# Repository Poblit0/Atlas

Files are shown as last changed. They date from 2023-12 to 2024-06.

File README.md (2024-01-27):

# MiniAtlas
Projet de robotique Polytech - Promotion ROB3 2023/2024

De DELFLY Agathe et MAUVOISIN Paul

## Idée principale
Créer des robots d'entrepôt autonomes capables de stocker et restituer des colis grâce à Arduino

## Motivations
Ce premier projet a pour objectif de nous faire découvrir divers aspects de la robotique

Les problématiques de ce robot semblent couvrir un panel de fondamentaux :
- Un système de déplacement dans l’espace
- Un système de préhension capable de manipuler des colis
- Une mémoire contenant l’emplacement des colis enregistrés
- Un système de communication pour échanger avec ses homologues

## Origine du nom
Le robot transporte les colis sur sa face supérieure, ce qui peut être considéré comme son dos
    
Cette position nous rappelait le mythe d'Atlas qui portait la Terre sur son dos, d'où le choix de ce nom pour notre robot

## Matériel (par robot)
### Carte électronique
- 1 carte Arduino UNO
- 1 pont en H

### Moteurs
- 2 servomoteurs
- 2 moteurs CC
  
### Capteurs
- 5 capteurs IR

### Modules
- 1 module de communciations RF

### Matériels complémentaires
- 1 interrupteur
- 1 boîtier d'alimentation
- 1 roulette à billes

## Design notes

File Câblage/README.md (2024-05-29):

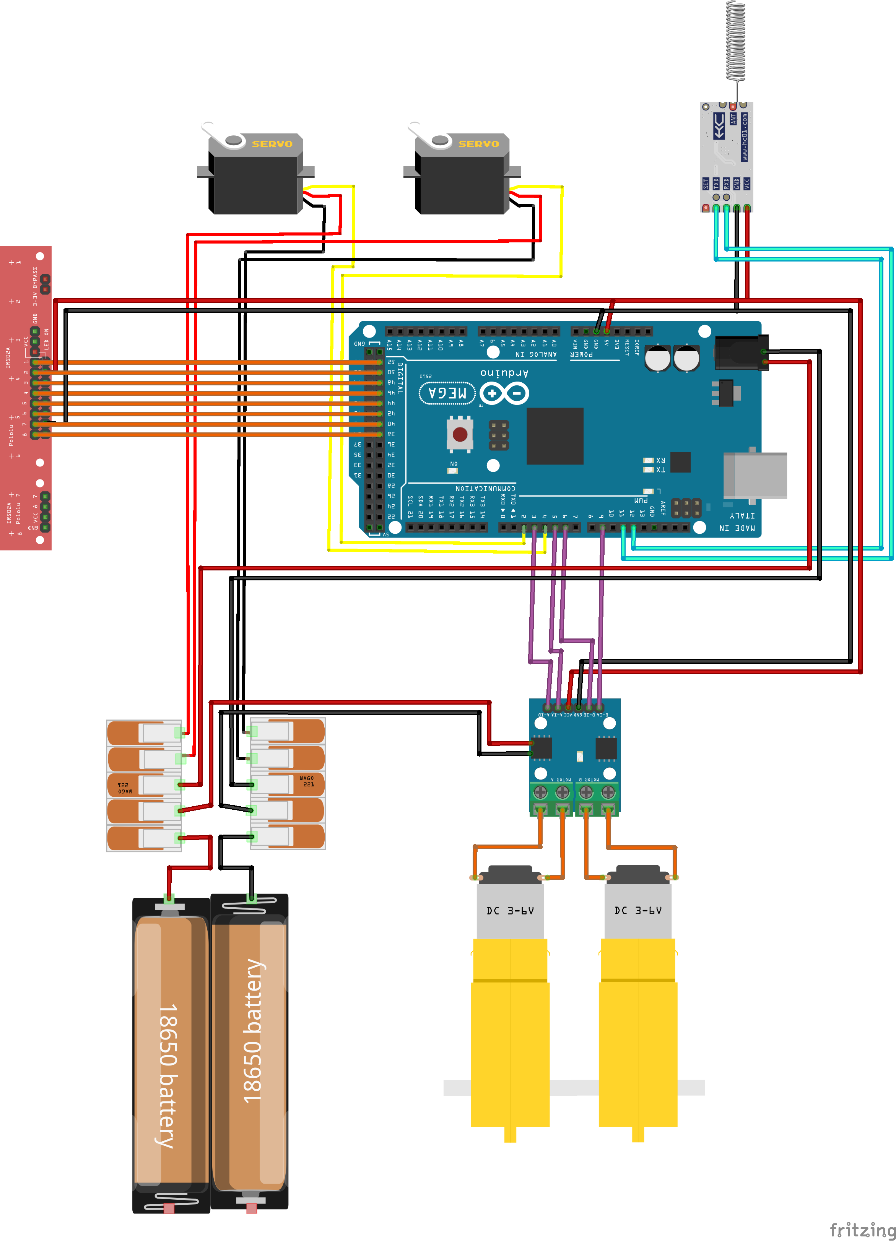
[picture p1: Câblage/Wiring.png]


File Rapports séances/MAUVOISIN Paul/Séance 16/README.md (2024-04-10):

## Forums pour envoyer des données de l'Arduino vers la Jetson

[Forum Nvidia](https://forums.developer.nvidia.com/t/questions-on-jetson-nano-arduino-i2c-communication/111277/3)

[Forum Arduino](https://forum.arduino.cc/t/arduino-jetson-nano-i2c-communication-failure/1008558)

## Librairies sources

['smbus'](https://pypi.org/project/smbus2/) pour Python

['Wire'](https://www.arduino.cc/reference/en/language/functions/communication/wire/) pour Arduino

## Vidéos d'explication pour l'usage des librairies

[pour l'utilisation de Wire](https://www.youtube.com/watch?v=2W4lViDKhpE)

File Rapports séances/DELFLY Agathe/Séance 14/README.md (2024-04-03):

## Suivi de ligne avec PID



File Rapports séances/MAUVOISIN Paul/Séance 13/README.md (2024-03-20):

## Liens utilisés pour le contrôle des servomoteurs
1er [Lien GitHub](https://github.com/JetsonHacksNano/ServoKit) pour le contrôle des servomoteurs

2nde [Vidéo tutorielle](https://www.youtube.com/watch?v=8YKAtpPSEOk&ab_channel=PaulMcWhorter) pour tenter de contourner l'erreur du 1er lien

## GIF de la Téléopération
Précisions :
- Le joystick de droite pilote la roue droite, respectivement à gauche, ce qui explique pourquoi le robot ne se déplace que de cette manière, car je filme avec mon téléphone dans la main gauche.
- Le joystick est très sensible, ce qui explique pourquoi de légers mouvements font bouger le robot si rapidemment.



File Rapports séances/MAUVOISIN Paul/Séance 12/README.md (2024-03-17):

# Sources retenues

## Réaliser le suivi de ligne par caméra
- [Lien le plus direct](https://jetbot.org/master/examples/road_following.html), par Nvidia JetBot eux-mêmes
- [Vidéo explicative et détaillée](https://www.youtube.com/watch?v=VY7m4lPIOj0&ab_channel=NVIDIADeveloper) du lien Nvidia précédent
- [Un répertoire GitHub](https://github.com/abuelgasimsaadeldin/Jetbot-Road-Following-and-Collision-Avoidance) qui permettra, à termes, la fusion du suivi de ligne et l'évitement d'obstacle qui pourrait être utile

## Actionner les servomoteurs
- [Site internet](https://jetsonhacks.com/2019/07/22/jetson-nano-using-i2c/), où se trouve également une vidéo pour comprendre l'utilisation des servomoteurs à travers un bus I2C et le PCA9685
- [Seconde vidéo](https://www.youtube.com/watch?v=8YKAtpPSEOk&ab_channel=PaulMcWhorter), permettant de prendre en mains les servomoteurs avec le même matériel

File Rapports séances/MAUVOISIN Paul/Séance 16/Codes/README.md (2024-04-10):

### Le fichier "Master.txt" est le code Python de la Jetson Nano

### Le fichier "Slave.ino" est le code Arduino

*Les dénominations Master et Slave font références aux rôles de chacune des cartes dans la communication I2C*

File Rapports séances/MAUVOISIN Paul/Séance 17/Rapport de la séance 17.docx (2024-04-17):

Rapport de la séance 17

16 avril 2024

Objectif de séance :

- Réaliser le code pour la communication I2C entre Arduino et Jetson Nano
- Réaliser le suivi de ligne par caméra à la place du suivi de route

Tout d’abord, après ma documentation sur les librairies ‘smbus’ pour Python et ‘Wire’ pour Arduino, je suis parvenu à obtenir un code fonctionnel.

Celui-ci fonctionne avec un capteur IR branché sur l’Arduino.

Si le capteur voit du noir, la communication I2C permet à la Jetson de recevoir l’information et affichera ‘True’, à l’inverse, elle affichera ‘False’ si le captera ne voit pas du noir.

Les codes (Python et Arduino) sont fournis dans le répertoire de la séance 17.

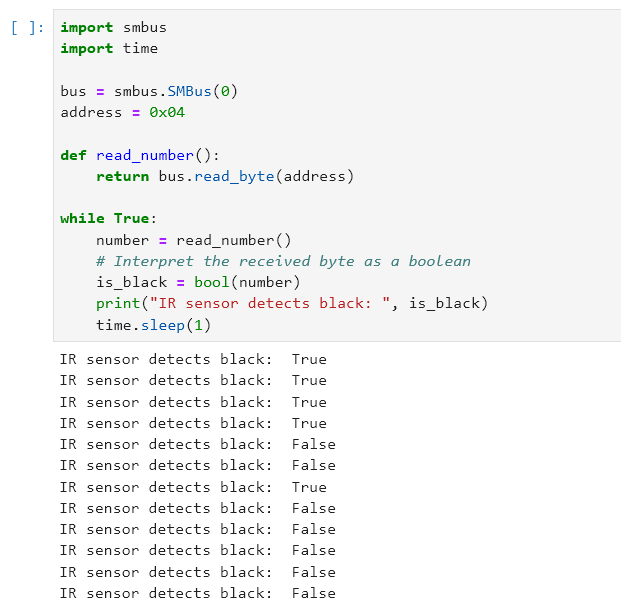
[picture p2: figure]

L’objectif sera de placer des marqueurs noirs détectés par le capteur IR pour arrêter les moteurs du moteur pendant le dépôt ou la réception d’un colis.

J’ai ensuite pris les photos pour réaliser le suivi de ligne par caméra. Or, avec la même quantité de photo que pour le suivi de route, soit 200 photos, le résultat n’est pas très concluant. Il sera donc nécessaire de faire plus de photos pour réessayer le suivi de ligne, car il est préférable que nos 2 robots suivent une ligne, plutôt que l’un suive une ligne et l’autre une route, ce qui rendrait incompatible leur déplacement dans l’environnement de l’autre.

Cependant, dû au réseau de l’école, la latence entre la réalité et l’affichage de la caméra ne rend pas l’opération, de prendre les photos, fluides. C’est pourquoi je prendrai les autres photos depuis le réseau de mon domicile et je vais me renseigner maintenant sur l’achat d’un tapis avec un motif imprimé.

Si le suivi de ligne fonctionne, il sera possible de faire imprimer sur tapis via le site PixartPrinting, un entrepôt avec des dimensions parfaites et sans imperfections.

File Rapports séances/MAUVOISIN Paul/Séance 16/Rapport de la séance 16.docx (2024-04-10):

Rapport de la séance 16

9 avril 2024

Objectif de séance :

- Résoudre le problème de l’importation de ‘smbus’ pour réaliser la connexion I2C
- Imprimer des meilleurs supports servomoteurs
- Créer un code pour qu’un capteur IR connecté à l’Arduino mette en fonction le suivi de route du robot avec la Jetson

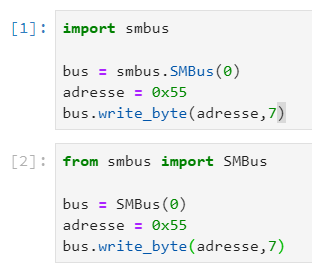
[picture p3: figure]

Tout d’abord, le problème ‘smbus’ a été résolu avant la séance grâce à l’aide de Nino Mulac en ROB4. Le problème était bénin, il en résultait uniquement de mon manque de connaissance en Python. Dans mon code, j’ai fusionné les 2 méthodes d’importation d’une libraire, ce qui évidemment rend le code obsolète. Pour que le code fonctionne, il faut utiliser l’un des 2 codes ci-dessous.

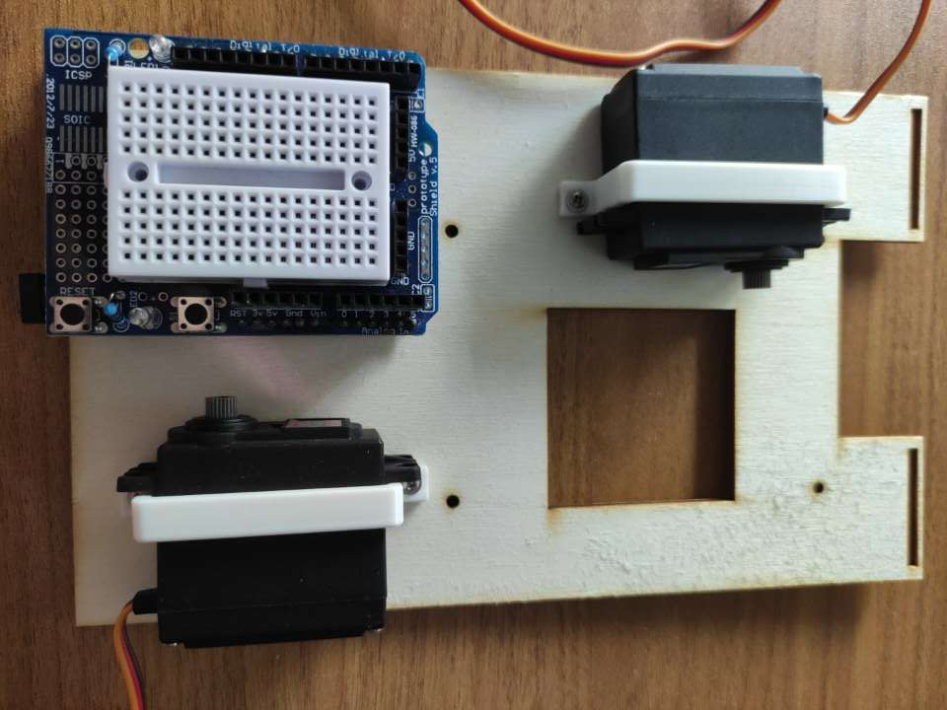
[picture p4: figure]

Ensuite, je me suis attelé à imprimer en 3D des supports pour les servomoteurs. En effet, actuellement, les servomoteurs sont vissés à des chutes de découpeuse laser qui sont collés à la planche du robot. Ce choix était fait dans l’objectif de ne pas gâcher du PLA lorsqu’il était possible de récupérer du bois provenant de chutes. Cependant, ce choix reste rudimentaire, et il est préférable d’avoir un support servomoteurs plus performants.

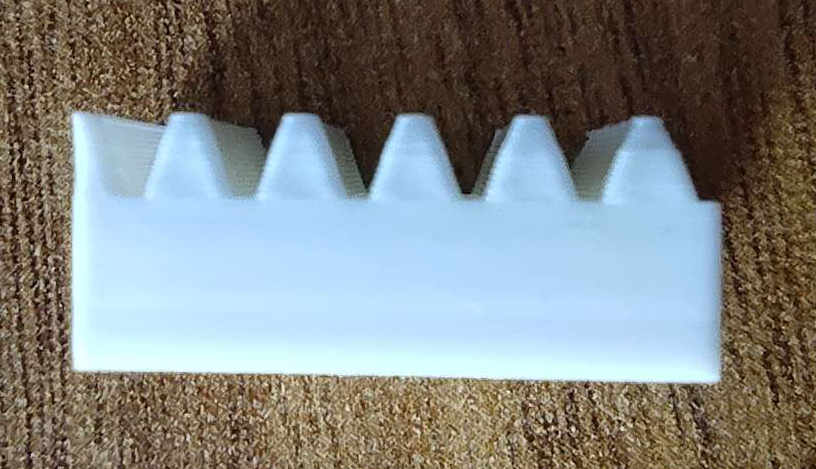
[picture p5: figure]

Il sera également nécessaire d’agrandir les rails qui sont entrainés par l’engrenage fixé aux servomoteurs afin d’augmenter la surface de contact avec la plaque élévatrice. C’est une tâche que je n’ai pas effectuée, car elle n’était pas prévue, et également facile à exécuter.

Enfin, j’ai passé le reste de la séance à essayer la communication I2C entre la Jetson Nano et la carte Arduino.

Je suis parvenu à faire afficher un chiffre envoyé par la Jetson vers l’Arduino.

En effet, il n’est pas nécessaire d’envoyer plus d’information qu’un chiffre, ou bien un boolean. L’objectif est de laisser le suivi de route de la Jetson actif lorsqu’elle reçoit True de la part de l’Arduino, et arrête le suivi de route pour se stopper lorsqu’elle reçoit False de la part de l’Arduino. Le reste du fonctionnement du robot pourra s’effectuer avec l’Arduino.

Pour choisir si True ou False est envoyé, il sera nécessaire d’ajouter un capteur IR orienté vers le bas, ainsi qu’une marque spécifique et bien placé dans l’entrepôt miniaturisé pour indiquer au robot où se trouvent les emplacements d’arrêt (Accueil et Étagère).

Cependant, alors qu’il a été aisé de trouver un code pour envoyer une information avec la Jetson et la réceptionnée avec l’Arduino, il m’est bien plus compliqué de trouver un code qui effectue l’opération inverse : envoyer une information avec Arduino et la réceptionner avec la Jetson.

Je suis parvenu à trouver 2 forums qui exposaient le même problème mais avec 2 résolutions différentes. Cependant, aucune des 2 propositions ne fonctionnaient. La raison est que je ne parviens pas encore à m’approprier correctement les fonctions des librairies utilisées que sont ‘smbus’ pour la partie Python de la Jetson ainsi que ‘Wire’ pour la partie Arduino.

Je vais donc me documenter sur les sites référençant ces librairies, ainsi que visionner des vidéos explicatives de leurs utilisations.

Sources indiquées dans le README.md de cette séance.

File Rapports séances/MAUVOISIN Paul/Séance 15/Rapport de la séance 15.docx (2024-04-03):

Rapport de la séance 15

2 avril 2024

Objectif de séance :

- Récolter les images pour la banque de données
- Essayer le suivi de ligne par caméra

1er blocage : les délais

Tout d’abord, cette séance, il y avait l’oral de présentation à réaliser. Un problème, que j’avais déjà pu expérimenter chez moi, est survenu.

Ce problème est la présence d’un délai entre les moments où l’ordinateur reçoit et envoie des informations au robot. Celui-ci peut dépasser les 5 minutes dans les pires environnements comme j’ai pu expérimenter en classe lors de la présentation.

Le plus visible est la caméra. En effet, il est clairement limpide que la caméra présente parfois un délai immense, car elle retranscrit l’affichage d’évènement passé il y a plusieurs minutes.

Aussi, il est visible sur les moteurs. Lorsqu’on lance les moteurs, puisqu’on les coupe, il s’écoule plusieurs minutes avant que le robot ne s’arrête.

Heureusement, j’avais réalisé une vidéo afin de contourner ce problème lors de la présentation, mais il cela reste un problème majeur dans la suite du développement. Cette même vidéo se trouve dans le GIF du README.md qui atteste du fonctionnement en très bonne voie de perfection du robot.

2ème blocage : les problèmes d’importations

Après la présentation, je me suis attelé à réaliser la communication I2C entre la Jetson Nano et la carte Arduino. Pour cela, j’ai reproduit ce que nous avions fait dans notre cours d’informatique, qui avait très bien fonctionné sur une autre image sur une autre carte miniSD.

Cependant, les mêmes codes (qui indiquent que la Jetson Nano est le Master et la carte Arduino le Slave) et les mêmes manipulations qui fonctionnaient sur l’autre carte miniSD, ne fonctionne pas ici.

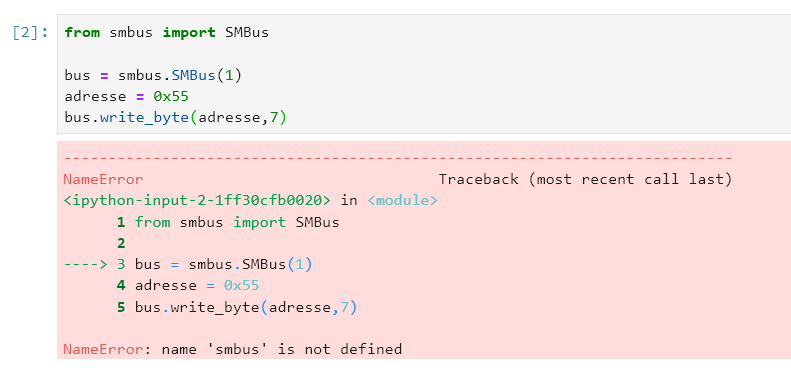
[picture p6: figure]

Cette erreur induit que le problème concerne l’importation de la librairie ‘smbus’, essentielle pour le fonctionnement de la communication I2C.

J’ai passé le reste de la séance à tenter de résoudre le problème sans succès.

La solution proposée sur tous les sites, est l’importation de la librairie via le terminal, mais encore une fois, c’est un échec.

Pourtant, rien n’indique une erreur lors de l’importation.

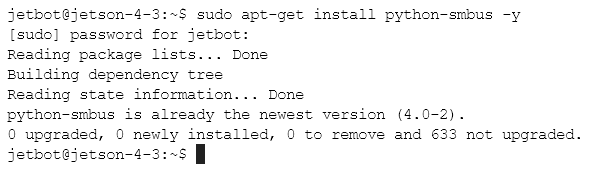
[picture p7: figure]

Ensuite, un étudiant en informatique membre d’Hirondelle Technologies m’a soumis l’idée d’utiliser ‘Python venv’, qui serait susceptible de résoudre mon problème. Ma fin de séance a donc été dédié à commencer à m’informer sur cette solution.

Objectif de la prochaine séance :

- Résoudre le problème de l’importation de ‘smbus’ pour réaliser la connexion I2C
- Réaliser / Adapter le code pour que le Jetbot opère dans l’entrepôt (ajout d’un capteur IR, du contrôle des servomoteurs, du module de communication RF)
- Essayer un suivi de ligne par caméra, plutôt qu’un suivi de route, qui rendrait plus simple l’usage de nos 2 robots sur le même entrepôt

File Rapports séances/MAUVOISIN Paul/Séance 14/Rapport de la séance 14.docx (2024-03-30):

Rapport de la séance 14

19 mars 2024

Objectif de séance :

- Récolter les images pour la banque de données
- Essayer le suivi de ligne par caméra

Information concernant les servomoteurs :

Tout d’abord la dernière séance, j’avais des problèmes avec l’activation des servomoteurs par le biais de la Jetson Nano. Cependant, lors de notre dernier cours d’informatique, nous avons appris à faire communiquer la Jetson Nano avec la carte Arduino avec de l’I2C.

Par conséquent, il semble être une bonne option de rajouter sur notre nouveau robot une carte Arduino, afin de faciliter l’activation des servomoteurs, mais aussi la communication entre nos robots.

En effet, le fait que la Jetson Nano nécessite d’être codé en Python me ralentit dans l’avancée du projet car il ne s’agit pas d’un langage de programmation que je maitrise.

Ainsi, il semble être une bonne option de rajouter une carte Arduino au robot afin d’utiliser les servomoteurs, les modules de communication RF, et potentiellement d’autres capteurs qui seraient nécessaires au bon fonctionnement du robot dans l’entrepôt miniaturisé.

Suivi de route par caméra : (Source dans le README.md)

Première tentative :

Place maintenant, au travail réalisé dans la séance qui concerne le suivi de route par caméra.

Pour rappel, ce fonctionnement se base sur des Jupyter Notebooks, qui sont l’équivalent de bibliothèques d’informations où se trouve du code et des explications concernant leur fonctionnement. Ces Jupyter NoteBooks sont des publications de Nvidia sur l’apprentissage et la découverte des notions d’intelligence artificielle.

La première étape est de prendre une multitude de photos.

Celles-ci ont pour objectif de créer une banque d’image qui servira à l’entrainement de l’intelligence artificielle. Pour ce premier test, j’ai pris une centaine de photos du robot placer à divers endroits de la piste avec différents angles selon où il se trouve.

De plus, au moment de prendre la photo, il faut utiliser une manette (avec du code présenté lors du dernier rapport), qui permet d’indiquer sur chaque image l’endroit vers lequel devrait se diriger le robot.

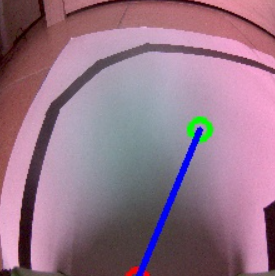
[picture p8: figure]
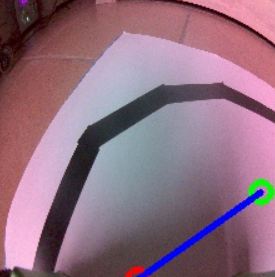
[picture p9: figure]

Quelques photos en guise d’exemple :

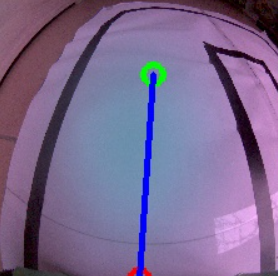
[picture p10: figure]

Ensuite, arrive l’étape d’entrainement de l’IA.

Pour se faire, le Jupyter Notebooks se sert de la librairie : torch. Cette librairie permet de réaliser de l’apprentissage machine. C’est donc grâce à cette librairie qu’il est possible de convertir la banque d’image en un réseau de neurone.

Enfin, le test pratique.

Pour cette première tentative, le résultat est peu glorieux. Les seules choses qui semblent légèrement fonctionner sont les virages. En effet, lors d’un virage, le robot effectue une forte rotation conforme à ce qu’il devrait réaliser pour tourner dans le virage. Cependant, il ne parvient pas à continuer sa route après le virage.

En conclusion de cette première tentative, il semble que de légères modifications pourront déjà grandement améliorer la précision du robot.

En effet, je pense qu’agrandir la largeur de la route permettrait au robot de mieux appréhender l’arrivée des virages. De plus, il est préférable de recentrer la piste vers l’intérieur du panneau, car de légères sorties de route conduisent à la chute du robot.

Seconde tentative :

Ainsi, j’ai effectué une deuxième tentative avec une nouvelle piste plus large et plus centrée. J’ai repris les photos, au nombre de 200 cette fois-ci. Et en réalisant la même manipulation que précédemment, le résultat est nettement mieux (voir GIF dans le README.md). En effet, le suivi est quasi fonctionnel, il semble que la caméra devrait être plus relevée afin que l’anticipation des virages s’effectue de plus loin.

Troisième tentative :

Je vais donc réaliser une troisième tentative avec 200 nouvelles photos en relevant la caméra. Cependant, je n’ai pas le temps de finaliser la prise de ces 200 nouvelles photos durant la séance, je n’ai donc pas de vidéo ni d’arguments qui confirme que le fait de relever la caméra améliore la précision du robot.

Objectif de la prochaine séance :

- Avoir un suivi de route parfaitement fonctionnel
- Créer une liaison I2C entre la carte Arduino et la Jetson Nano
- Ajouter des capteurs sur le robot pour qu’il s’arrête aux endroits souhaités (emplacement de dépôt des colis)

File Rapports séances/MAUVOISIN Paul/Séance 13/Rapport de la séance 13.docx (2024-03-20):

Rapport de la séance 13

19 mars 2024

Objectif de séance :

- Actionner les moteurs avec les codes de base fournis
- Parvenir à actionner les servomoteurs
- Découvrir l’utilisation de la caméra

Actionner les moteurs avec les codes de base fournis :

Cette section est essentiellement présente pour évoquer la première interaction avec la JetSon et le système Jupyter fournis par Nvidia pour débuter avec la JetSon.

Jupyter est une interface permettant d’aborder facilement les notions de bases implémentées par Nvidia telle que le contrôle des moteurs. Celle-ci est remplie d’informations complémentaires afin de comprendre plus en détails le fonctionnement d’une simple ligne de code puisque le langage n’est plus Arduino, mais du Python.

Après avoir essayé et constaté le bon fonctionnement des moteurs, je préfère ne pas m’attarder sur cette notion déjà étudiée, car celle-ci est très semblable à Arduino grâce à Jupyter, ainsi que la librairie Python fourni par Nvidia.

Tentative d’activation des servomoteurs :

Cette rubrique est indispensable à détailler contrairement à la précédente à propos des moteurs pour 2 raisons.

La première raison : l’activation de servomoteurs n’est pas traitée par l’interface Jupyter, il va donc être nécessaire d’acquérir des renseignements ailleurs que par les ressources fournies par Nvidia.

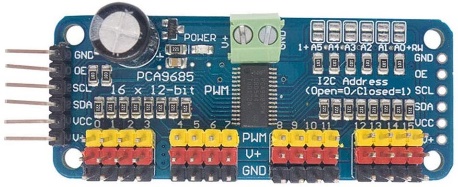
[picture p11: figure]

La seconde raison : les servomoteurs sont facilement implémentés avec Arduino, car il s’agit d’un composant de base pour comprendre les rudiments de cette carte, ce qui n’est pas le cas pour la JetSon.

Il est alors possible d’actionner les servomoteurs via un bus I2C, par le module PCA9685 :

Cependant, lors de la procédure d’installation pour aboutir à une rotation des servomoteurs, une erreur que je ne parviens pas à contourner s’est montré.

Il existe un forum qui répertorie mon problème sur le site de Nvidia, seulement la solution apportée n’a pas résolu mon problème. Je préfère le laisser sur le côté pour l’instant afin d’essayer la téléopération ainsi que la caméra.

Informations supplémentaires sur l’erreur à résoudre avant la prochaine séance :

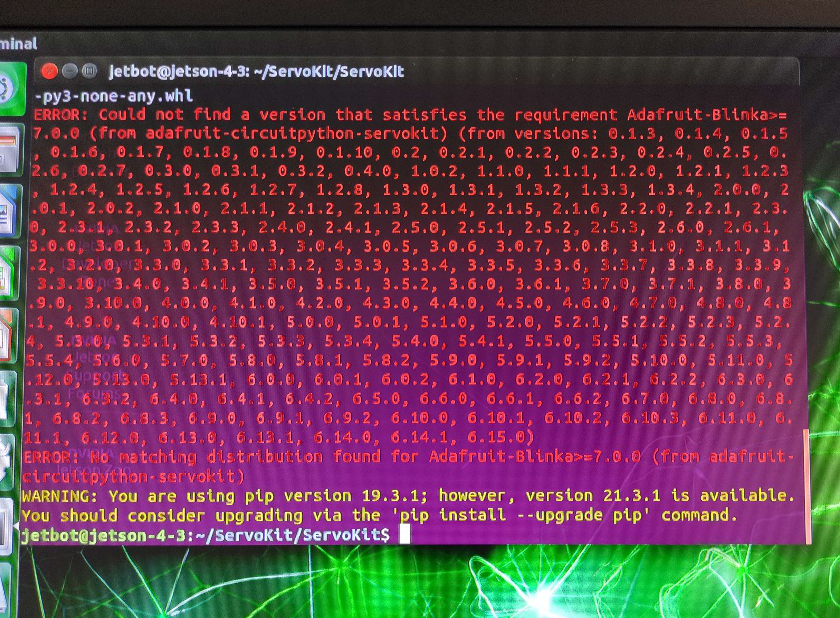
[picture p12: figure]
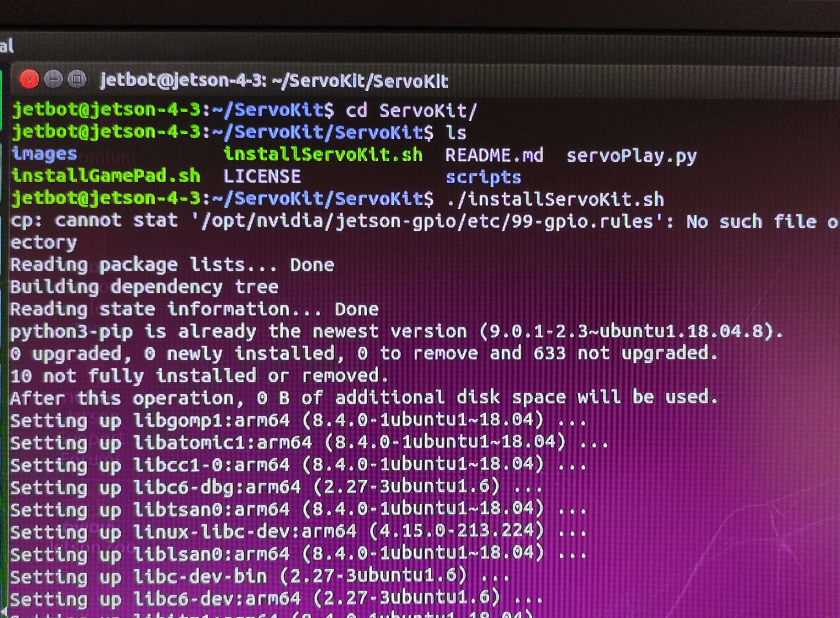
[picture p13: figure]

Pour l’activation des servomoteurs, j’ai tout d’abord suivi un premier tutoriel d’un répertoire sur GitHub, qui possède également une vidéo explicative.

Lors d’une étape, il faut procéder à l’activation d’un fichier qui me rend l’erreur ci-contre.

La solution de Nvidia ne résolvant pas le problème, j’ai opté pour un second tutoriel qui était uniquement une vidéo explicative, qui m’a conduit à la même erreur. Il sera donc nécessaire d’approfondir les recherches avant la prochaine séance pour éviter de rester bloqué à cette étape très longtemps.

Téléopération du robot en prévision de suivi de ligne par caméra :

A première vue, cette section n’a pas de sens avec notre projet, car le robot doit être autonome. Cependant, l’interface Jupyter possède des ressources de nouveau intéressantes : un suivi de ligne par caméra à l’aide d’une IA.

Seulement, le bon fonctionnement, ainsi que la bonne compréhension des explications quant à cette rubrique de suivi de ligne, nécessite tout d’abord de comprendre la téléopération du robot.

Quel est le lien entre le suivi de ligne par caméra et la téléopération ?

Le suivi de ligne par caméra nécessite d’avoir une banque d’image indiquant le mouvement à effectuer selon l’environnement, pour cela un curseur est placé sur l’overlay de la caméra et l’utilisation d’une manette de contrôle (téléopération) permet de positionner rapidement le curseur sur l’image. Cette fonction est donc très utile pour minimiser le temps entre chaque image pour compléter rapidement, et ainsi en plus grande quantité, la banque de données.

Ainsi, après avoir suivi les informations de Jupyter, le robot est désormais pilotable à l’aide de la manette de contrôle (un GIF est disponible dans le README.md pour illustrer).

Objectif de séance prochaine :

- Résoudre le problème de code des servomoteurs
- Récolter les images pour la banque de données
- Essayer le suivi de ligne par caméra

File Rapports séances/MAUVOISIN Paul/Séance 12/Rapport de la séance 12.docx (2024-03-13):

Rapport de la séance 12

12 mars 2024

Objectif de séance :

- Monter le JetBot
- Identifier les modifications à apporter au JetBot pour le rendre compatible au projet
- Étudier la possibilité du suivi de ligne avec la caméra du JetBot

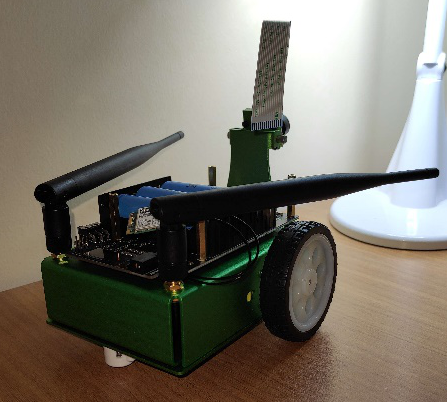
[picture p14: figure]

Tout d’abord, j’ai réussi à monter rapidement le châssis du JetBot :

Ainsi, j’ai pu constater que la dimension des antennes du robot pourrait poser un problème, étant donné qu’il sera nécessaire d’ajouter des servomoteurs au-dessus de la carte JetSon Nano. Cependant, celle-ci sont rabattables, donc il est simplement nécessaire de considérer que nous pouvons agrandit le robot, mais pas l’élargir en dessous des antennes.

Ensuite, il est important de trouver des renseignements sur l’utilisation de la JetSon, pour ça j’ai listé les éléments qu’il faudra parvenir à utiliser sans passer par la carte Arduino ni du code Arduino :

- Réaliser un suivi de ligne par caméra
- Actionner les servomoteurs

Un cours sur la manière de parvenir à connecter la JetSon à notre ordinateur nous sera dispensé vendredi, en fin de semaine, c’est pourquoi je n’ai pas listé cette étape. Tout comme l’étape : actionner les moteurs ; qui n’est pas listé, car il est fourni avec le JetBot des codes de bases permettant de le faire.

Également, je préfère consacrer cette séance sur la récolte d’informations pour à la fois gagner du temps sur l’apprentissage des réalisations ci-dessus, mais aussi afin d’éviter de perdre du temps en essayant de réaliser une implémentation inutile (comme le suivi de ligne par capteurs IR, comme sur l’ancien châssis, alors que le JetBot possède une caméra et de nombreuses sources sur son utilisation).

Réaliser le suivi de ligne par caméra :

Il existe de nombreuses variantes du traitement de l’image de cette caméra afin de réaliser un suivi de ligne. Cependant, parmi les sources trouvées, l’une d’elle provient de Nvidia directement, ce qui semble être la solution à opter. Elle n’est peut-être pas la plus simple d’utilisation, mais leur plateforme de support est riche en informations et aussi très actives si je venais à moi-même devoir leur poser une question.

Actionner les servomoteurs :

Après des recherches, il semble nécessaire d’utiliser un driver pour l’utilisation des servomoteurs contrairement à Arduino. Parmi ceux trouvés, l’un d’eux se démarque, il s’agit du PCA9685 de chez Adafruit. Par conséquent, il est nécessaire d’un acquérir un avant de pouvoir utiliser le code pour actionner les servomoteurs.

Objectif de séance prochaine :

- Actionner les moteurs avec les codes de base fournis
- Parvenir à actionner les servomoteurs (si la commande est arrivée à temps sinon le temps sera consacré à la caméra)
- Découvrir l’utilisation de la caméra (et commencer si possible le suivi de ligne)

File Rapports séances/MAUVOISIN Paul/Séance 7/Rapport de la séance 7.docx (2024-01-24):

Rapport de la séance 7

23 janvier 2024

Objectif de séance :

- Aligner les roues et les roulettes à billes
- Changer la carte Arduino UNO pour une Arduino MEGA 2560
- Modifier les déplacements du robot grâce à 2 nouveaux capteurs IR pour qu’il se place au centre des intersections

Tout d’abord, dans le weekend précédent la séance, j’ai limé l’intérieur des réceptacles pour les roulettes à billes, dans le but d’aligner parfaitement les 2 roues et les 2 roulettes à billes.

Le résultat est très satisfaisant, mais pas parfait, et celui-ci ne semble pas améliorable.

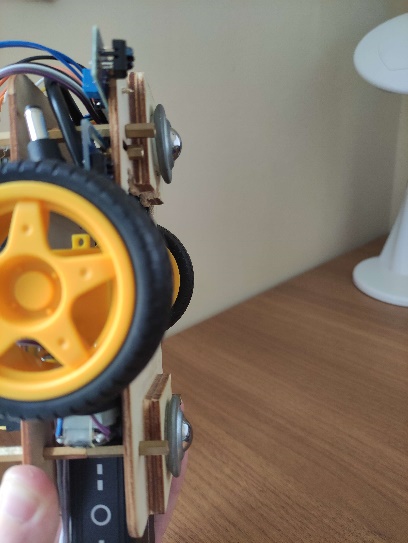
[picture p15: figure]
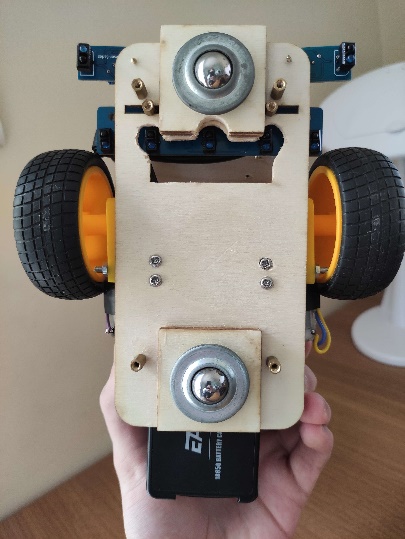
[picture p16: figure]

Par conséquent, il semble préférable de conserver ce résultat, car la partie supérieure du robot, ainsi que le poids du colis, permettront à ce que tous les éléments aient un bon contact avec sol.

Ensuite, il est nécessaire de remplacer notre Arduino UNO par une Arduino MEGA 2560, car notre robot requiert l’utilisation de 2 nouveaux capteurs analogiques, d’un interrupteur, ainsi qu’un module de communication RF. Or, notre carte actuelle ne possède plus assez de PIN numérique.

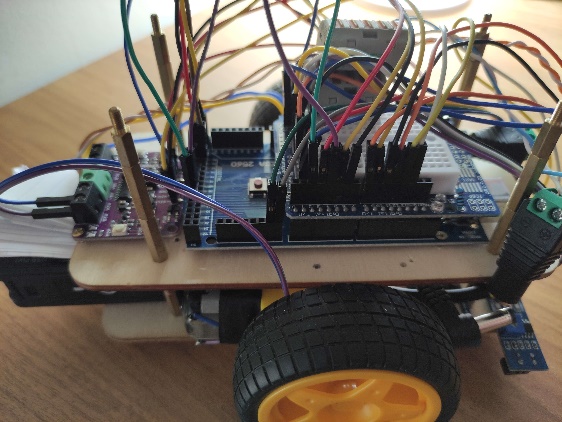
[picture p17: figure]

Enfin, la majeure partie de mon temps durant cette séance a été tournée vers le changement du mode de déplacement du robot.

A présent, lorsque notre robot rencontre une intersection, il décide de continuer tout droit jusqu’à ce que les deux nouveaux capteurs IR détectent les marqueurs prévus pour que le robot se trouve au centre de l’intersection.

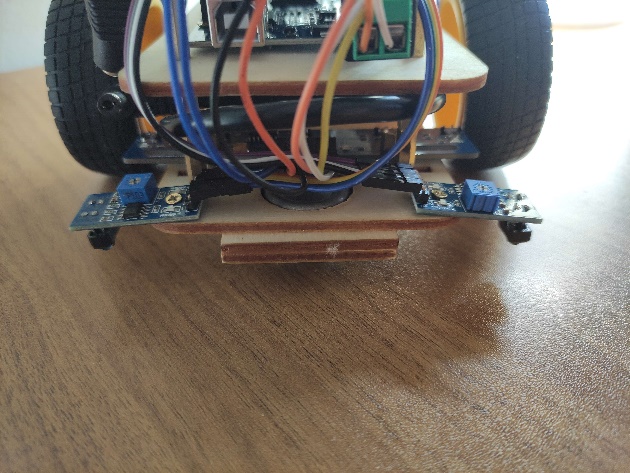
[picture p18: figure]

Une fois bien positionné, le robot s’arrête, et prend la décision de tourner sur lui-même jusqu’à ce que les capteurs IR de la bande de capteurs détectent la ligne à suivre (s’il tourne à droite ce sera le capteur 2 et s’il tourne à gauche ce sera le capteur 4)

Cependant, la mise en œuvre n’est pas un succès, pour une raison que je ne parviens pas à comprendre, sachant que les nouveaux capteurs ont été testés sur un autre programme plus simple et sont donc fonctionnels.

Je résoudrai ce problème avant la prochaine séance, grâce à la pause de la semaine de ski.

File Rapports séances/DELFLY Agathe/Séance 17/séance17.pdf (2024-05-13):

Séance 17 :

Objectifs de séance :

- Tester le programme avec les servomoteurs et la communication RF
- Modifier les étages du robot

Tout d’abord, nous avons remplacé les supports en bois qui permettaient de fixer les servomoteurs à l’étage 2, par des supports réalisés par mon binôme à l’imprimante 3D, car les supports en bois se décollaient et il n’était plus possible d’utiliser les servomoteurs.

Ensuite, j’ai redessiné sur Inkscape les différents étages du robot. En effet, l’étage 0 devait être modifié suite au changement de capteurs. Les étages 1 et 2 devaient être modifiés pour avoir la même taille que l’étage 0.

De plus, après avoir testé le programme, j’ai constaté plusieurs problèmes dans le code. J’ai donc dû modifier le programme qui contenait plusieurs erreurs liées au fonctionnement des servomoteurs ainsi qu’à la communication RF.

Le robot est donc maintenant capable de se rendre à l’étagère qui est indiquée par l’utilisateur et de récupérer ou déposer un colis puis de revenir à l’accueil.

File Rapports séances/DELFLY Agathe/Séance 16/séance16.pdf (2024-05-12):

Séance 16 :

Objectif de séance :

- Modifier le programme en utilisant la communication RF et les servomoteurs

Tout d’abord, les pin des modules RF n’étaient plus soudés, il a donc fallu les souder de nouveau et nous avons aussi soudé les pin au module RF qui sera utilisé pour le deuxième robot.

Ensuite, j’ai ajouté au programme le code réalisé par mon binôme concernant la communication RF. J’ai aussi modifié le programme pour activer les servomoteurs au bon moment.

Désormais, l’utilisateur indique une lettre qui correspond à un objet, si cet objet est placé sur une des étagères, le robot reçoit la lettre de l’étagère sur laquelle est placé l’objet, sinon, il s’agit d’un objet à déposer sur une des étagères.

Donc, lorsque le robot se trouve à l’accueil, il attend de recevoir la lettre R ou D pour savoir s’il va récupérer ou déposer un colis puis la lettre A ou B qui correspond à l’étagère vers laquelle il doit se diriger.

Par exemple, si le robot reçoit les lettres D et A, lorsqu’il est à l’accueil, les servomoteurs soulèvent la palette sur laquelle se trouve le colis, le robot se rend à l’étagère A, il dépose la palette sur l’étagère grâce aux servomoteurs puis repart. Une fois arrivé à l’accueil, le robot attend de nouveau de recevoir les lettres R ou D et A ou B.

Objectif de la prochaine séance : Tester le programme

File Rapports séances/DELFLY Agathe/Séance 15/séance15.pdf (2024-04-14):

Séance 15 :

Objectifs de séance :

- Modifier les coefficients du correcteur PID
- Modifier le programme pour déposer et récupérer le colis

Tout d’abord, afin que le robot soit capable d’aller jusqu’à l’étagère A ou B puis revenir à l’accueil pour la démonstration pour l’oral, j’ai de nouveau réalisé plusieurs essais pour déterminer les coefficients adaptés pour le correcteur PID.

Ensuite, j’ai modifié le programme pour permettre au robot de déposer ou récupérer un colis.

Quand le robot doit déposer un colis, il fait donc fonctionner les servomoteurs qui feront lever la palette sur laquelle se trouve le colis, lorsque le robot se trouve à l’accueil. Ensuite, lorsque le robot atteindra l’étagère A ou B, le robot s’arrêtera et fera fonctionner les servomoteurs pour descendre la palette et la déposer sur l’étagère, puis repartira à l’accueil.

Lorsque le robot doit récupérer un colis, il se dirigera d’abord vers l’étagère sur laquelle se trouve le colis. Ensuite, il va donc faire fonctionner les servomoteurs quand le robot sera en dessous de l’étagère, afin de soulever la palette. Une fois le colis récupéré, le robot reviendra à l’accueil.

Il faudra donc tester le programme à la prochaine séance.

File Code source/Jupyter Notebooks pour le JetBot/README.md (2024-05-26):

## Voici les 3 Jupyter Notebooks originaux qui ont été utilisés afin de réaliser le suivi de route

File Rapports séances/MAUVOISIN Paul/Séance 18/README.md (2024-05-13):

## Exempté de rendu de rapport pour cause de participation à la Coupe de France de Robotique 2024



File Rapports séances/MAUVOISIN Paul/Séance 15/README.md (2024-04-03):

## Amélioration du suivi de route par caméra



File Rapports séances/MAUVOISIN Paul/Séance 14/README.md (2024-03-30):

### [Source du suivi de route](https://github.com/NVIDIA-AI-IOT/jetbot/tree/master/notebooks/road_following)

### Le [fichier .zip](https://github.com/Poblit0/MiniAtlas/blob/main/Rapports%20s%C3%A9ances/MAUVOISIN%20Paul/S%C3%A9ance%2014/road_following_dataset_xy_2024-03-23_13-48-10.zip) contient les 200 photos de la seconde tentative (quelques exemples sont présents dans le rapport) 

### GIF du suivi de route - 2ème tentative.gif



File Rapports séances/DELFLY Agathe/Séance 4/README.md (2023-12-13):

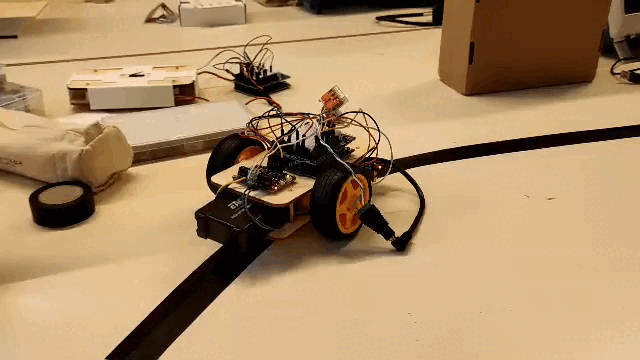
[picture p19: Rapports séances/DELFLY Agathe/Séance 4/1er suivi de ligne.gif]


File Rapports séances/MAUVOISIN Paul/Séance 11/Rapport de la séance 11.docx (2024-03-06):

Rapport de la séance 11

5 mars 2024

Objectif de séance :

- Finaliser le code de communication RF
- Faire le point sur l’avancement du projet et prendre conscience de l’évolution

Tout d’abord, concernant le code de communication RF, l’affichage rendu à l’utilisateur laissait à désirer à cause d’un problème inconnu.

Après des recherches sur internet pour trouver l’origine du problème, il semble que le problème provient des retours chariots. En effet, on ne demande à l’utilisateur que d’entrée un caractère, mais cela ne correspond pas à ce que perçoit le code, exemple :

Lorsque l’utilisateur envoie ‘A’, ce qui est réellement envoyé est ‘A\r’.

Ayant trouvé l’origine du problème, le code est enfin parfaitement fonctionnel, ci-dessous un exemple d’échange :

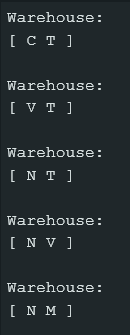
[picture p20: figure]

Entrepôt d’origine : Contient un colis ‘C’ et un colis ‘T’

Utilisateur rentre ‘C’, le robot reçoit R puis A, donc va Récupérer en A

Utilisateur rentre ‘N’, le robot reçoit D puis A, donc va Déposer en A

Utilisateur rentre ‘T’, le robot reçoit R puis B, donc va Récupérer en B

Utilisateur rentre ‘M’, le robot reçoit D puis B, donc va Déposer en B

Et la réception de ces lettres modifie des variables au sein du programme du robot pour lui assigner les actions qu’il doit réaliser Capture d’écran du programme de réception du Robot :

Ensuite, il me semble important de faire un point sur le projet.

D’après mon ressenti personnel, le projet a eu un bon lancement, suivi d’un d’une baisse de rythme depuis le mois de janvier. Ainsi, il me parait impératif d’appliquer des changements majeurs afin que le projet redevienne dynamique.

Le souhait initial de fabriquer entièrement le robot nous-même, sans l’utilisation de châssis déjà existant, permettait de gagner en expérience sur l’utilisation de la découpeuse laser, ainsi que des modules de bases, tels que les servomoteurs et les ponts en H par exemple.

Je suis satisfait du résultat de cette décision, cependant l’acquisition d’un châssis déjà optimisé permettra une meilleure base et une meilleure qualité de perspective du robot, car la base que nous avons nous-mêmes conçut limite le potentiel du projet par des restrictions de la qualité de notre base.

Par conséquent, il semble préférable de changer de châssis, ce qui implique une refonte avancée du robot.

Parmi les châssis trouvés, il en existe un adapté pour accueillir une JetSon, ce qui pourrait être une excellente option pour à terme quitter Arduino pour cette nouvelle carte plus puissante. De plus, il est équipé d’une caméra et possède des dimensions semblables à celles de notre robot actuel, il s’agit du JetBot.

Cela permettrait de rattraper au plus vite le retard afin de retrouver un robot capable de suivre une ligne efficacement avec les capteurs IR.

Mais aussi, le châssis est aisément modulable, ce qui offre la possibilité de nouvelles perspectives qui rendraient le projet réellement intéressant, fonctionnel et qualitatif, notamment grâce à la caméra et la JetSon.

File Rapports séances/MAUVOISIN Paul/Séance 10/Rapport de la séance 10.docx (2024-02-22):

Rapport de la séance 10

21 février 2024

Objectif de séance :

- Modifier le robot pour qu’il retourne sur son ancien modèle 3 points d’appui
- Elargir la plaque inférieure pour ajouter d’autres supports moteurs qu’il faut designer

Lors de la dernière séance, le robot avait des difficultés lors de ses déplacements. Parfois, les roues n’étaient que partiellement en contact avec le sol, ce qui impactait directement sa vitesse. De plus, les moteurs qui possèdent chacun un unique support s’affaissent vers l’intérieur du robot.

Par conséquent, Mr Masson m’a fait part d’un modèle de support qui peut s’ajouter au côté extérieur du robot, ce qui consolidera parfaitement la stabilité des moteurs.

Pour cela, il est nécessaire d’élargir également la plaque inférieure pour que les moteurs soient à fleur de rebord.

Pour ce qui concerne la plaque inférieure, j’ai avancé les moteurs pour que les roues soient placées à l’avant et j’ai conservé uniquement la roulette à billes qui était placée à l’arrière en faisant en sorte qu’elle soit le plus au centre possible de là où l’alimentation se trouvera.

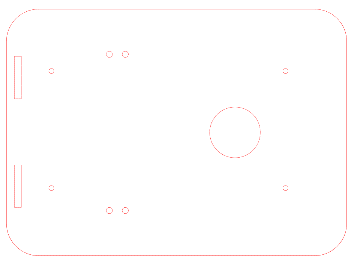
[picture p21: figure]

Pour le design des supports moteurs, ils peuvent être réalisés en utilisant les vis qui sont déjà nécessaires pour les supports métalliques. Mais, dans cette perspective, il faut que ces supports possèdent une excroissance qui viendra maintenir le support contre la plaque inférieure du robot.

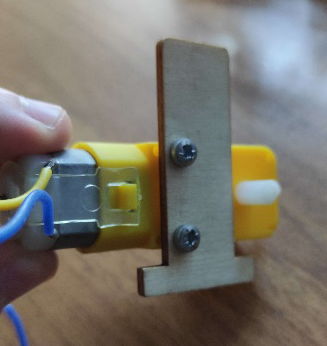
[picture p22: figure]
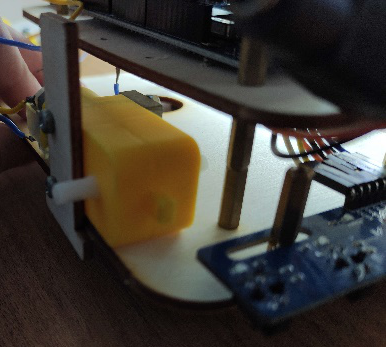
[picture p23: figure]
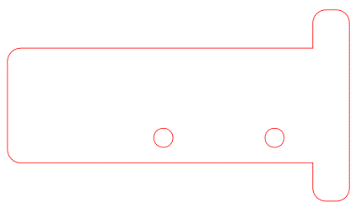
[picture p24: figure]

Cependant, les 2 fils d’un des moteurs se sont dessoudés, et je n’ai pas eu le temps de les ressouder pour tester le code de ma binôme.

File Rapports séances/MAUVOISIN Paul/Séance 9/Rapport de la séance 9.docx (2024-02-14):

Rapport de la séance 9

13 février 2024

Objectif de séance :

- Réaliser un système guidage complexe
- Réaliser la communication entre l’Ordinateur de contrôle et le Robot

Tout d’abord, j’ai pu tester le dernier système de guidage circulaire réalisé qui finalement n’était pas plus performant que le précédent.

Par conséquent, il est préférable d’arrêter de chercher des solutions possédant une réalisation facile, mais plutôt un système complexe qui sera performant. C’est pourquoi j’ai opté pour un guidage crémaillère, celui-ci sera d’une précision quasi infaillible.

Celui réalisé n’a pas été conçu de zéro, en effet, j’ai tout d’abord cherché des fichiers STL sur internet pour voir si un modèle était utilisable. C’est ainsi que j’ai trouvé une crémaillère convenable à notre projet. Les simples modifications réalisées ont été d’agrandir l’engrenage, de raccourcir le rail dentelé, et de créer le guidage du rail qui n’était pas dans le fichier d’origine.

Un GIF est disponible dans le README pour voir le système en mouvement.

Ensuite, j’ai pu commencer le programme de communication entre l’Ordinateur central et le Robot. L’objectif est que l’utilisateur donne le minimum d’information au Robot car celui-ci doit être autonome.

Par conséquent, le code Arduino ne réclame qu’à l’utilisateur une lettre.

S’il souhaite Déposer un colis, alors il doit lui donner une lettre, qui peut être l’initial de son contenu qui n’est pas déjà contenu dans la liste.

S’il souhaite Entreposer un colis, alors il doit donner la lettre du colis pour savoir lequel récupérer.

Le code, au moment du rendu, ne fonctionnement pas encore parfaitement.

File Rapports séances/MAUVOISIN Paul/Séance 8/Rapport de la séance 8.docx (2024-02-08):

Rapport de la séance 8

7 février 2024

Objectif de séance :

- Réaliser un nouveau système de guidage
- Souder les PIN aux modules de radio fréquence
- Débuter la communication radio fréquence

Tout d’abord, lors de la dernière séance notre professeur de mécanique est passé nous voir, et nous expliqué pourquoi notre guidage de la plaque élévatrice n’est pas optimale.

Le problème auquel nous sommes confrontés est l’arc-boutement, en effet, comme nous utilisons 4 guidages dans chaque angle de notre robot, et que les planches du robot ne sont pas parfaitement droites, les entretoises se coincent dans les systèmes de guidages, ce qui fait qu’elles ne redescendent pas complètement s’il n’y a pas de poids sur la plaque élévatrice.


Par conséquent, en guise de solution, il est possible de réduire le nombre de guidage, et aussi les rapprocher entre eux. Donc, j’ai modélisé 2 guidages circulaires qui sont positionnés plus au centre de du robot.


Ensuite, j’ai soudé les PIN aux modules de radio fréquence, et je les ai essayés avec un code trouvé sur internet. Hors le code ne fonctionnait pas au début sans que je sache pourquoi. Et après de multiple essaies, le problème venait de la soudure qui n’était pas assez bien réalisé, mais à présent les modules fonctionnent.


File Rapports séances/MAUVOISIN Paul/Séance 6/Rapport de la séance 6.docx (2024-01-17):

Rapport de la séance 6

16 janvier 2024

Objectif de séance :

- Rectifier les problèmes soulevés par Mr Masson et Mr Peter lors de l’oral de fin de semestre

Suite à l’échange réalisé avec nos enseignants, plusieurs points améliorables ont été soulevés. Par conséquent, nous préférons ne pas réaliser ce que nous avions prévu pour la séance, mais plutôt passé notre temps sur les changements que nos professeurs nous ont proposés.

Premier point :

Entre autres, les capteurs IR sont placés à l’avant de notre robot, ce qui fait que notre robot se met à tourner au croisement d’une intersection lorsque l’avant y arrive. Ainsi, Mr Masson nous a conseillé de trouver une solution pour que le robot place son centre au-dessus du croisement, de s’arrêter, tourner sur lui-même, et seulement ensuite se remettre à suivre la ligne. Cette stratégie limitera les problèmes de détachement de ligne, ce qui causera une perdition du robot, le mettant hors service sans assistance humaine.


Dans un premier temps, nous allons rapprocher les capteurs IR des roues, afin que la détection des croisements se trouve déjà plus au centre du robot. Ensuite, il faudra trouver d’autres capteurs, afin de mieux contrôler les trajectoires du robot (pour mieux le guider, et le rendre plus précis).


Du fait du peu de temps accordé, j’ai juste eu le temps d’imprimer rapidement un exemplaire, et ce n’est que le lendemain que j’ai le temps de le réassembler, en remarquant que mes mesures sont erronées, mais en limant, elle est tout de même fonctionnelle.

Second point :

De plus, il nous a été conseillé d’utiliser une seconde roulette à billes, dans le but d’avoir 4 appuis au sol, au lieu de 3 actuellement. Cette stratégie permettra une meilleure stabilité, et donc un meilleur contrôle des trajectoires, mais il faudra rigoureusement positionner les 2 roues et les 2 roulettes à billes, pour que celles-ci soient toutes en contact avec le sol.


Dans un premier temps, nous allons recentrer les roues, et positionner la nouvelle roulette à billes à l’avant de notre robot. Il est préférable que celle-ci soit plus basse que les roues, parce qu’il est plus simple de la remonter que de baisser les roues.

Enfin, puisque le robot doit être entièrement démonté pour installer la nouvelle planche du niveau 0, j’en profite pour changer la carte Arduino UNO qui a le port USB qui se décroche.

En effet, il a mal été soudé sur la carte électronique, ce qui provoque une mauvaise connexion en permanence, ce qui empêche très souvent le téléversement.

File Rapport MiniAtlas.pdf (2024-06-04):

DELFLY Agathe | Filière ROB3
MAUVOISIN Paul | 2023-2024
Rapport Projet “MiniAtlas”

Sommaire
- Présentation (page 1)
- Schéma électrique (page 2)
- Logigramme et détails de fonctionnement (page 2)
- Coût du projet (page 3)
- Problèmes rencontrés (page 4)
- Perspectives d’amélioration (page 5)
- Conclusion (page 6)
- Sources (page 6)

Présentation du Projet

Dans le contexte actuel de l'industrie, l'automatisation des entrepôts est devenue une priorité pour de nombreuses entreprises. Les robots d'entrepôt sont des machines conçues pour effectuer des tâches répétitives et pénibles, telles que le déplacement de palettes de marchandises. N’ayant pas besoin de repos, ils permettent également de gagner du temps en étant actif 24h/24h. Dans notre projet, nous avons pour objectif de concevoir un essaim de robots d'entrepôt capables de déplacer des colis de manière efficace et autonome.

Notre robot, nommé MiniAtlas, est un robot de type AGV (Automatic Guided Vehicle), actuellement guidé par des capteurs infrarouges analogiques et suivant une bande noire sur le sol. Cette méthode de guidage est simple, efficace et plus fiable que l’utilisation d’une caméra qui serait dotée d’une intelligence artificielle pour effectuer le suivi de ligne.

Notre essaim est actuellement composé de deux robots, mais nous prévoyons d'en ajouter davantage à l'avenir. Ces robots communiquent avec un ordinateur central, qui stocke toutes les informations sur les étagères et les emplacements des colis. Grâce à une communication radio fréquence, l'ordinateur central décide quel robot envoyer, s’il doit déposer ou récupérer un colis et à quelle étagère il doit se rendre, en fonction des requêtes de l’utilisateur.
Les robots communiquent aussi entre eux afin d'éviter les collisions.

Pour déplacer les colis, notre robot se glisse sous une palette sur laquelle se trouve le colis. Deux servomoteurs prennent alors le relais pour soulever la palette et la transporter jusqu'à l'emplacement désiré. Cette méthode simple et efficace permet à notre robot d’être très compact. Les servomoteurs utilisent une liaison pignon-crémaillère pour effectuer l’élévation.

Par conséquent, notre robot est capable de suivre une ligne pour se déplacer, de communiquer avec un ordinateur central pour savoir les tâches qu’il doit effectuer et enfin avoir un actionneur capable de récupérer et de déposer des colis.


Rapport Projet “MiniAtlas”

Schéma électrique

Logigramme et détails de fonctionnement

Rapport Projet “MiniAtlas”

L'ordinateur central est responsable de la gestion du contenu des étagères dans l'entrepôt. Il enregistre les informations dans des listes et les affiche à l'utilisateur. Pour déplacer un colis, l'utilisateur entre le numéro du robot, l'initiale de l'objet disposé sur l'une des étagères ou une nouvelle initiale s'il s'agit d'un nouvel objet qu’il souhaite entreposer. L'ordinateur central envoie alors automatiquement par radiofréquence les informations nécessaires aux robots, c'est-à-dire le numéro du robot, la lettre correspondant à l’étagère où le robot doit se rendre et la lettre correspondant à la récupération ou à l’entreposage du colis.

Chaque robot compte le nombre d'intersections qu'il a franchies, ce qui lui permet de connaître sa position dans l'entrepôt. Pour chaque étagère, une liste contenant les actions à effectuer à chaque intersection est prédéfinie. À chaque intersection, selon l'étagère sélectionnée et le nombre d'intersections déjà franchies, le robot effectue une rotation à gauche ou à droite ou continue de rouler. Chaque robot se rend à une étagère et rejoint son point de départ après avoir effectué l’opération souhaitée par l’utilisateur.

Pour éviter les collisions, à chaque intersection, le premier robot envoie sa position au deuxième robot qui s'arrête ou continue de rouler en fonction de sa position et de celle du premier robot.

Coût du projet


Tous les prix sont ceux du site AliExpress.com Prix total pour 2 robots actuellement opérationnels : 150,24€

Rapport Projet “MiniAtlas”


Comme indiqué, nous prenons la base de 38k€ de salaire pour 1600h de travail

Total du coût de la main d’oeuvre : 6 175€

Coût total du projet : 6 325,24€

Problèmes rencontrés

L'un des défis majeurs que nous avons rencontrés dans ce projet était la gestion du poids et de l'équilibre du robot. En raison de sa petite taille compacte, il était difficile de placer tous les composants nécessaires dans le gabarit du robot tout en maintenant un centre de gravité équilibré. Nous avons dû effectuer plusieurs itérations de conception et de placement des composants pour trouver une solution viable.

Un autre défi important était le cable management. Avec un espace limité dans le robot, il était difficile d'organiser correctement les câbles et les fils pour éviter les enchevêtrements et les courts-circuits. Nous avons utilisé des nappes de fils pour améliorer la lisibilité et la gestion des câbles, mais cela ne résout pas complètement le problème.

La répartition des masses des composants était également un facteur important à prendre en compte. Nous avons dû nous assurer que la batterie et les autres composants lourds étaient placés au-dessus des roues motrices pour éviter que le robot n'entre en résonance et ne puisse effectuer un suivi de ligne efficace.

Également, nous avons rencontré un problème lié à la liaison pignon-crémaillère des servomoteurs. En effet, cette liaison doit permettre de soulever une charge importante tout en étant de petite taille. Cependant, nous avons rapidement constaté que la surface de contact entre le rail qui se déplace et la plaque était trop petite, ce qui fragilise l'appui plan. Pour résoudre ce problème, nous avons décidé d'agrandir la surface de contact entre le rail et la plaque.

Enfin, nous avons rencontré des difficultés dans la mise en œuvre du suivi de ligne à l'aide de capteurs IR numériques. Bien que nous ayons initialement opté pour cette approche en raison de sa simplicité et de son faible coût, nous avons constaté que la fiabilité et la précision du suivi de ligne étaient insuffisantes pour répondre à nos besoins. Ainsi, l’utilisation de capteurs IR analogiques a permis d’explorer d'autres approches et algorithmes pour améliorer la performance du suivi de ligne, ce qui a nécessité la réalisation d’un correcteur proportionnel dérivé.

Rapport Projet “MiniAtlas”

Perspectives d’amélioration

Pour améliorer notre projet de robot d'entrepôt, plusieurs pistes peuvent être envisagées. Tout d'abord, l'agrandissement de l'entrepôt et l'augmentation de la taille et du nombre de robots permettraient de se rapprocher davantage des conditions réelles d'utilisation. Cependant, cela nécessiterait également de revoir l'algorithme de fonctionnement pour pouvoir gérer un grand nombre de robots simultanément. Il serait également judicieux d'ajouter des capteurs supplémentaires, tels que des capteurs à ultrasons ou des lidars, pour éviter les collisions entre les robots et avec les éventuels obstacles ou personnes présentes dans l'entrepôt.

Ensuite, l'amélioration de l'aspect esthétique du robot pourrait être une piste intéressante. Le remplacement du contreplaqué par du plexiglas donnerait un aspect plus professionnel et moderne au robot. De plus, la réalisation d'un cable management permettrait de mieux organiser les différents fils et câbles, ce qui faciliterait la maintenance et le dépannage éventuel du robot. Enfin, la conception d'une armature pour isoler les composants électroniques de l'extérieur permettrait de protéger le robot.

Aussi, bien que nous ayons rencontré des difficultés dans la mise en œuvre d'un suivi de ligne par caméra et intelligence artificielle avec la Jetson Nano, nous croyons toujours que cette approche a un potentiel pour les robots d'entrepôt à plus grande échelle. En effet, un robot plus grand pourrait permettre une meilleure intégration de la caméra et des capteurs, ce qui rendrait l'option de suivi de ligne par IA plus viable et complémentaire à des capteurs. Cette perspective de réétude de la combinaison IA caméra avec un robot d'une échelle commerciale pour un entrepôt réel est donc très intéressante.

D’autre part, nous avons également constaté que notre conception actuelle d'étagères ne permettait l'accueil que d'un unique colis, ce qui n'est pas optimal économiquement pour un entrepôt. En effet, dans un entrepôt, c'est la surface qui fait le coût et non pas la hauteur. Ainsi, pour réduire les coûts, il est important d'optimiser l'utilisation de l'espace disponible en hauteur. Pour cette raison, nous pensons qu'il serait judicieux de concevoir des étagères plus grandes et plus hautes, capables d'accueillir plusieurs colis, ce qui permettrait une utilisation plus efficace de l'espace disponible dans l'entrepôt, mais pour cela, nous devons trouver un nouveau moyen pour que le robot puisse récupérer les colis ou alors de nouveaux designs d’étagères pour que le robot monte sur l’étagère.

Enfin, l'ajout de fonctionnalités logicielles supplémentaires pourrait également être envisagé. Par exemple, la mise en place d'un système de sauvegarde automatique du contenu des étagères permettrait de ne pas perdre les données en cas de coupure de courant ou de défaillance de l'ordinateur central.

Rapport Projet “MiniAtlas”

Conclusion

Après plusieurs mois de travail, le robot remplit toutes les conditions du cahier des charges. Il dispose d’un système de suivi de ligne fiable et efficace. Cependant, nous sommes conscients que des améliorations peuvent encore être apportées, notamment en ce qui concerne l'utilisation de capteurs supplémentaires pour renforcer la fiabilité de l'évitement de collisions entre les robots.

Nous avons également mis en place un système de préhension de colis fonctionnel, mais nous pensons qu'il serait judicieux de concevoir des étagères plus adaptées pour faciliter les opérations de dépôt et de récupération de colis. Nous sommes cependant très satisfaits de la communication entre l'ordinateur central et les robots, qui fonctionne de manière optimale et qui est déjà prête pour une utilisation à grande échelle.

Maintenant que nous avons atteint nos premiers objectifs, nous pensons qu'il est temps de voir plus grand et d'envisager une extension de notre projet. Nous pourrions par exemple agrandir l'entrepôt, augmenter la taille et le nombre de robots pour une utilisation dans des conditions réelles.

Sources

Lien pour la réalisation du correcteur en position avec la bande de 8 capteurs analogiques IR : https://www.pololu.com/docs/0j19/all

Lien pour la réalisation du suivi de ligne avec caméra et intelligence artificielle grâce à la Jetson Nano et le châssis Jetbot de Nvidia : https://github.com/NVIDIA-AI-IOT/jetbot/tree/master/notebooks

Lien pour la première émission et réception d’informations avec les modules de radiofréquences HC-12 :
https://howtomechatronics.com/tutorials/arduino/arduino-and-hc-12-long-range-wireless-communication-module/ (https://howtomechatronics.com/tutorials/arduino/arduino-and-hc-12-long-range-wireless-communication-module/)

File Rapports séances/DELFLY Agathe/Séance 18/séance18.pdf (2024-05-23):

Séance 18 :

Objectifs de séance :

- Modifier le programme du robot 1
- Modifier le programme qui envoie les consignes aux robots
- Commencer le programme du deuxième robot
- Tester la communication RF avec les deux robots

Tout d’abord, j’ai modifié le programme de l’ordinateur qui avait été réalisé par mon binôme. Au lieu de rentrer une lettre, l’utilisateur devra rentrer le chiffre 1 ou 2 qui correspond au robot 1 ou 2 puis la lettre de l’objet à déposer ou récupérer. J’ai aussi modifié la taille de l’entrepôt dans chaque programme pour ajouter les étagères C et D.
Avec la communication RF, les robots recevront tous les 2 trois caractères. Le premier caractère correspond au robot choisi par l’utilisateur (1 ou 2), le deuxième caractère correspond à récupérer ou à entreposer un colis (R ou E) et le troisième correspond à l’étagère (A, B, C ou D).

Ensuite, j’ai modifié le programme du robot pour qu’il se mette en route seulement lorsqu’il reçoit comme premier caractère 1. J’ai ajouté le code pour la communication RF pour que le robot 1 envoie au robot 2 la dernière intersection qu’il a franchie, ce qui permet de connaître sa position.

Enfin, j’ai commencé le programme du deuxième robot à partir de celui du robot 1. Le robot 2 se mettra en route lorsqu’il reçoit comme premier caractère 2 et ne tiendra pas compte de la consigne destinée au robot 1. Ensuite, à certaines intersections, il attendra de recevoir la position du robot 1 pour vérifier qu’il ne se trouve pas sur son chemin et éviter une collision.

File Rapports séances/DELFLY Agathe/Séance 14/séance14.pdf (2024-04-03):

Séance 14 :

Objectifs de séance :

- Résoudre le problème des à-coups du robot
- Améliorer le suivi de ligne avec un correcteur PID

Pour commencer, j'ai remarqué que le robot avançait difficilement. En effet, lorsque le robot roule, la partie avant du robot se soulève, ce qui empêche les capteurs de bien détecter la ligne noire et le robot avance en faisant des à-coups. Pour remédier à ce problème, j’ai donc inversé le sens du robot. J’ai donc déplacé les capteurs de l’autre côté du robot, ce qui m’a obligée à modifier l’étage 0 du robot pour pouvoir fixer correctement la bande de capteurs.


Ensuite, j’ai déterminé le temps de rotation adapté pour permettre au robot d’être aligné avec la ligne noire après la rotation.

Ensuite, j’ai remarqué que le correcteur proportionnel n’était pas suffisant, j’ai donc ajouté la correction intégrale et dérivée. J’ai donc entrepris de nombreux essais pour déterminer les coefficients adaptés.

Donc, le robot est désormais capable d’aller jusqu’à l’étagère A ou B puis de revenir à l’accueil.

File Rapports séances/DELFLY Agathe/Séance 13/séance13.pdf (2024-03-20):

Séance 13 :

Objectifs de séance :

- Souder les pins sur la bande de capteurs QTR-8RC
- Fixer la bande de capteurs à l’avant du robot
- Réaliser le programme de suivi de ligne du robot avec un correcteur proportionnel

Pour commencer, j'ai remarqué que le suivi de ligne du robot laissait à désirer. Les performances n'étaient pas à la hauteur de nos attentes, avec des mouvements irréguliers et des déviations fréquentes par rapport à la trajectoire souhaitée.

Pour remédier à ce problème, j'ai entrepris de modifier le programme de suivi de ligne en y intégrant un correcteur proportionnel. Cette approche nous permettrait d'ajuster les corrections en fonction de l'erreur de suivi détectée par les capteurs infrarouges.

J’ai installé la bibliothèque QTRSensors qui permet de travailler avec les capteurs QTR-8RC. Dans le programme, je calibre les capteurs pendant dix secondes et j’allume la LED de l'Arduino pendant le calibrage. Pendant la phase de calibrage, il faut donc exposer chaque capteur aux lectures les plus claires et les plus sombres qu'ils rencontreront. Pour cela, il faut faire glisser les capteurs sur la ligne noire afin que chaque capteur puisse obtenir une lecture du degré d'obscurité de la ligne et du degré de clarté du sol. Ensuite, grâce à la fonction qtr.readLineBlack, le réseau de capteurs renvoie la position de la ligne noire, c’est-à-dire une valeur comprise entre 0 et 7000. Si la valeur est 3500, cela signifie que le réseau de capteurs se situe au centre de la ligne. Ensuite, je calcule l’erreur (3500 – position) puis la correction qui est proportionnelle à l’erreur. Enfin, les vitesses des moteurs des roues varient en fonction de la correction.

Pour finir, après avoir soudé les pins à la bande de capteurs QTR-8RC, j'ai procédé au remplacement des capteurs infrarouges analogiques, qui n’étaient pas parfaitement alignés ni idéalement placés, par la bande de capteurs à l'avant du robot.

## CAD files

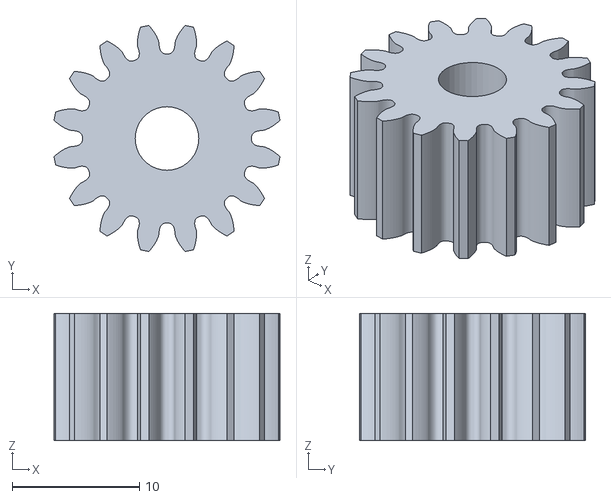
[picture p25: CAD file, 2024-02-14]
Rapports séances/MAUVOISIN Paul/Séance 9/Guidage Crémaillère/Engrenage.STL
17.8 x 17.8 x 10.0

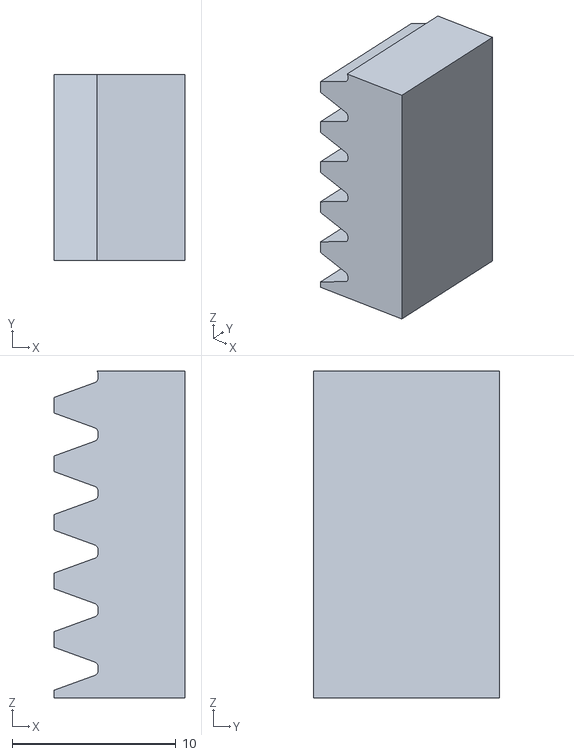
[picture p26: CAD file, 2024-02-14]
Rapports séances/MAUVOISIN Paul/Séance 9/Guidage Crémaillère/Rail.stl
7.99 x 11.4 x 20.0

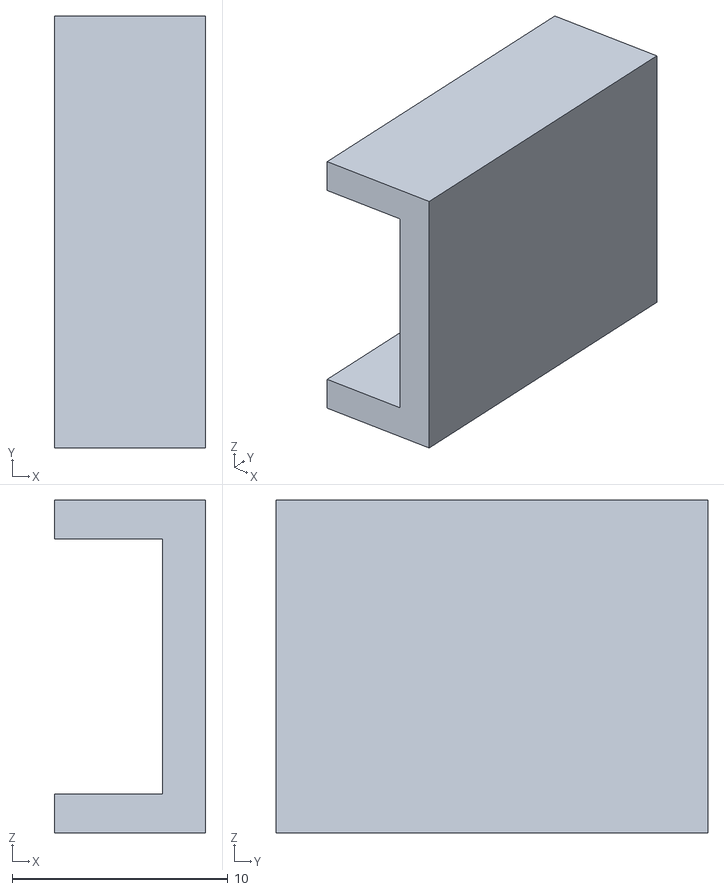
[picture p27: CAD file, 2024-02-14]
Rapports séances/MAUVOISIN Paul/Séance 9/Guidage Crémaillère/Guidage.stl
7.00 x 20.0 x 15.4

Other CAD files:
Rapports séances/MAUVOISIN Paul/Séance 2/Fichier Fusion360/Conduit entretoise et écrou v9.f3d
Rapports séances/MAUVOISIN Paul/Séance 3/Fichier Fusion360/interrupteur v4.f3d
Rapports séances/MAUVOISIN Paul/Séance 4/Fichier Fusion360/Grand guidage.f3d

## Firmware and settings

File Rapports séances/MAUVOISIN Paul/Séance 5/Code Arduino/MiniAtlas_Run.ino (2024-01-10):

//                                    //                           //
//                                    // DECLARATION DES VARIABLES //
//                                    //                           //

//Assignements aux PIN
//Pour les capteurs IR numeriques
const int pin_capteur1 = 8;
const int pin_capteur2 = 10;
const int pin_capteur3 = 11;
const int pin_capteur4 = 12;
const int pin_capteur5 = 13;
//Pour les moteurs
const int M1A = 3;
const int M2A = 6;
const int M1B = 5;
const int M2B = 9;

//Variables des vitesses de moteurs
int low_speed = 40;
int high_speed = 80;

//Variables de detection des capteurs numeriques
int valeur_capteur1 = 0;
int valeur_capteur2 = 0;
int valeur_capteur3 = 0;
int valeur_capteur4 = 0;
int valeur_capteur5 = 0;

//Variables pour les intersections
int step = -1;
bool go_A_or_B = true;                                                //Si false on veut aller en A, si true on veut aller en B
char go_A[8] = { 'L', 'R', 'R', 'C', 'R', 'R', 'L', 'A' };             //'L' pour Left, 'R' pour Right, 'S' pour Straight, 'A' pour Acceuil, 'C' pour Colis
char go_B[10] = { 'L', 'R', 'S', 'R', 'C', 'R', 'S', 'R', 'L', 'A' };  //'L' pour Left, 'R' pour Right, 'S' pour Straight, 'A' pour Acceuil, 'C' pour Colis
bool change_step = false;
bool read_currentTime = true;
int currentTime = 0;
bool former_sensor_color = false;
int cpt_switch_color = 0;


//                                    //                //
//                                    // FONCTION SETUP //
//                                    //                //


void setup() {

  //Les capteurs sont INPUT
  pinMode(pin_capteur1, INPUT);
  pinMode(pin_capteur2, INPUT);
  pinMode(pin_capteur3, INPUT);
  pinMode(pin_capteur4, INPUT);
  pinMode(pin_capteur5, INPUT);

  //Les moteurs sont OUTPUT
  pinMode(M1A, OUTPUT);
  pinMode(M2A, OUTPUT);
  pinMode(M1B, OUTPUT);
  pinMode(M2B, OUTPUT);

  //Démarrage Serial
  Serial.begin(9600);
  Serial.println("Initialisation");
  Serial.print("Step : ");
  Serial.println(step);

  delay(5000);
}


//                                    //               //
//                                    // FONCTION LOOP //
//                                    //               //


void loop() {
  global_detection();

  if (true_intersection() == true) {
    if (change_step == true) {
      change_step = false;
      step += 1;
      Serial.print("Step : ");
      Serial.println(step);
    }
    mapping();
  }

  else {
    change_step = true;
    simple_line();
  }
}


//                                    //                               //
//                                    // FONCTION POUR LA CARTOGRAPHIE //
//                                    //                               //


void mapping() {

  if (go_A_or_B == false) {
    if (go_A[step] == 'S') {
      forward();
    }
    if (go_A[step] == 'R') {
      intersection_rotate_right();
    }
    if (go_A[step] == 'L') {
      intersection_rotate_left();
    }
    if (go_A[step] == 'C') {
      stop();
      delay(10000);
    }
    if (go_A[step] == 'A') {
      stop();
      delay(100000);
      //acceuil();
    }
  }

  if (go_A_or_B == true) {
    if (go_B[step] == 'S') {
      forward();
    }
    if (go_B[step] == 'R') {
      intersection_rotate_right();
    }
    if (go_B[step] == 'L') {
      intersection_rotate_left();
    }
    if (go_B[step] == 'C') {
      stop();
      delay(10000);
    }
    if (go_B[step] == 'A') {
      stop();
      delay(100000);
      //acceuil();
    }
  }

  delay(600);
}


//                                    //                                   //
//                                    // FONCTION DE SUIVI DE LIGNE SIMPLE //
//                                    //                                   //


void simple_line() {
  if (valeur_capteur2 == LOW) {
    turn_left();
  }

  else if (valeur_capteur4 == LOW) {
    turn_right();
  }

  else {
    forward();
  }
}


//                                    //                       //
//                                    // FONCTION INTERSECTION //
//                                    //                       //


bool true_intersection() {
  if ((valeur_capteur1 == HIGH) && (valeur_capteur5 == HIGH)) {
    read_currentTime = true;
    return false;
  }
  if ((valeur_capteur1 == LOW) || (valeur_capteur5 == LOW)) {
    if (read_currentTime == true) {
      read_currentTime = false;
      currentTime = millis();
    }
    if ((millis() - currentTime) > 100) {
      return true;
    }
  }
}


//                                    //                              //
//                                    // FONCTION DE ROTATION ACCEUIL //
//                                    //                              //


void acceuil() {
  if (read_currentTime == true) {
    read_currentTime = false;
    currentTime = millis();
  }
  if ((millis() - currentTime) > 1000) {
    while ((valeur_capteur2 == HIGH) && (cpt_switch_color >= 2)) {
      self_rotate();
    }
  }
}


//                                    //                                    //
//                                    // FONCTION D'ACTIVATION DES CAPTEURS //
//                                    //                                    //


void global_detection() {
  valeur_capteur1 = digitalRead(pin_capteur1);
  valeur_capteur2 = digitalRead(pin_capteur2);
  valeur_capteur3 = digitalRead(pin_capteur3);
  valeur_capteur4 = digitalRead(pin_capteur4);
  valeur_capteur5 = digitalRead(pin_capteur5);
}


//                                    //                                   //
//                                    // FONCTION DE CHANGEMENT DE COULEUR //
//                                    //                                   //

void switch_color() {
  if (valeur_capteur4 != former_sensor_color) {
    if ((valeur_capteur4 == HIGH)) {
      cpt_switch_color += 1;
    }
    if ((valeur_capteur4 == LOW) && (former_sensor_color = true)) {
      cpt_switch_color += 1;
    }
    former_sensor_color = valeur_capteur4;
  }
}


//                                    //                               //
//                                    // FONCTIONS POUR LE DEPLACEMENT //
//                                    //                               //


void stop() {
  low_speed = 0;
  analogWrite(M1A, 0);
  analogWrite(M2A, 0);
  analogWrite(M1B, low_speed);
  analogWrite(M2B, low_speed);
}

void forward() {
  analogWrite(M1A, 0);
  analogWrite(M2A, 0);
  analogWrite(M1B, high_speed);
  analogWrite(M2B, high_speed);
}

void turn_right() {
  analogWrite(M1A, 0);
  analogWrite(M2A, 0);
  analogWrite(M1B, high_speed);
  analogWrite(M2B, low_speed);
}

void turn_left() {
  analogWrite(M1A, 0);
  analogWrite(M2A, 0);
  analogWrite(M1B, low_speed);
  analogWrite(M2B, high_speed);
}

void self_rotate() {
  analogWrite(M1A, low_speed);
  analogWrite(M2A, 0);
  analogWrite(M1B, 0);
  analogWrite(M2B, low_speed);
}

void intersection_rotate_right() {
  analogWrite(M1A, 0);
  analogWrite(M2A, low_speed);
  analogWrite(M1B, high_speed);
  analogWrite(M2B, 0);
}

void intersection_rotate_left() {
  analogWrite(M1A, low_speed);
  analogWrite(M2A, 0);
  analogWrite(M1B, 0);
  analogWrite(M2B, high_speed);
}

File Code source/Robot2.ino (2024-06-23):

#include <QTRSensors.h>
#include <SoftwareSerial.h>
#include "Servo.h"

//Pour les servomoteurs
Servo servo1;
Servo servo2;

//Pour la communication RF
SoftwareSerial HC12(11, 12);  
char msg;
bool positionR1_recue = false;
int positionRobot1 = 0;

//Pour les capteurs
QTRSensors qtr;
const int nombreDeCapteurs = 8;
int valeursCapteurs[nombreDeCapteurs];

//Pour les moteurs
const int M1A = 3;
const int M2A = 6;
const int M1B = 5;
const int M2B = 9;
int vitesse = 80;

//Pour le correcteur
const double Kp = 0.01;
const double Kd = 0.5;
double erreurPrecedente = 0.0;
const int positionVoulue = 3500;

//Pour l'entrepot
char allerVersA[10] = {'A','D','T','G','C','G','G','D','G','A'}; 
char allerVersB[12] = {'A','D','T','T','G','C','G','T','G','D','G','A'};
char allerVersC[10] = {'A','D','T','D','C','D','D','G','G','A'};
char allerVersD[12] = {'A','D','T','T','D','C','D','T','D','G','G','A'};
char chemin[12];
char consigneRobot[2] = {'N','N'};
char consigneRobot1 = 'N';
char robot = '0';
int intersection = 0;

//Pour les rotations
long tempsPrecedent = 0;
long tempsActuel = 0;
int tempsRotation= 350;

void setup() {
  servo1.attach(2);
  servo2.attach(4);
  servo1.write(20);  
  servo2.write(5);
  qtr.setTypeRC();
  qtr.setSensorPins((const uint8_t[]){38, 40, 42, 44, 46, 48, 50, 52}, nombreDeCapteurs); 
  pinMode(M1A, OUTPUT);
  pinMode(M2A, OUTPUT);
  pinMode(M1B, OUTPUT);
  pinMode(M2B, OUTPUT);
  HC12.begin(9600);
  Serial.begin(9600);
  Serial.println("Initialisation");
  delay(2000);
  Serial.println("Début calibrage");
  calibrageCapteurs();
  Serial.println("Fin calibrage");
}

void loop() {
  //Si le robot 2 n'a pas reçu de consigne
  if ((consigneRobot[0] != 'R' && consigneRobot[0] != 'E') || (consigneRobot[1] != 'A' && consigneRobot[1] != 'B' && consigneRobot[1] != 'C' && consigneRobot[1] != 'D') || robot != '2'){
    if (HC12.available()) {
      msg = HC12.read();
      //Choix du robot (1 ou 2)
      if (msg == '1' || msg == '2'){
        robot = msg;
      }
      //Choix de l'étagère (A,B,C ou D)
      if (msg == 'A' || msg == 'B' || msg == 'C' || msg == 'D') {    
        consigneRobot[1] = msg;  
      }
      //Choix de la consigne (récupérer ou entreposer)
      if (msg == 'R' || msg == 'E'){
        consigneRobot[0] = msg;
      }
      //Consigne du robot 1
      if (robot == '1'){
        consigneRobot1 = consigneRobot[1];
        consigneRobot[0] = 'N';
        consigneRobot[1] = 'N';
      }   
    }
    if (consigneRobot[1] == 'A'){
      for(int i = 0; i < 10; i++){
        chemin[i] = allerVersA[i];
      }
    }
    if (consigneRobot[1] == 'B'){
      for(int i = 0; i<12; i++){
        chemin[i] = allerVersB[i];
      }
    }
    if (consigneRobot[1] == 'C'){
      for(int i = 0; i < 10; i++){
        chemin[i] = allerVersC[i];
      }
    }
    if (consigneRobot[1] == 'D'){
      for(int i = 0; i < 12; i++){
        chemin[i] = allerVersD[i];
      }
    }
  }
  else {
    //Si le robot est à l'accueil
    if (intersection == 0){
      if(consigneRobot[0] == 'E'){
        leverPalette();
      }
      //Tant que les robots sont à proximité l'un de l'autre et risquent d'entrer en collision, le robot 2 n'avance pas
      while (positionRobot1 == 0 || positionRobot1 == 1 || ((positionRobot1 == 5 || positionRobot1 == 6 || positionRobot1 == 7) && (consigneRobot1 == 'A' || consigneRobot1 == 'C')) || ((positionRobot1 == 7 || positionRobot1 == 8 || positionRobot1 == 9) && (consigneRobot1 == 'B' || consigneRobot1 == 'D'))){
        arret();
        if (HC12.available()) {
          msg = HC12.read();
          positionRobot1 = msg - '0';
        }
      } 
    }
    unsigned int position = qtr.readLineBlack(valeursCapteurs);
    //Si les capteurs détectent une intersection
    if ((valeursCapteurs[0] == 1000 && valeursCapteurs[1] == 1000 && valeursCapteurs[2] == 1000 && valeursCapteurs[3] == 1000) || (valeursCapteurs[7] == 1000 && valeursCapteurs[4] == 1000 && valeursCapteurs[5] == 1000 && valeursCapteurs[6] == 1000)){
      intersection = intersection + 1;
      tempsPrecedent = millis();
      while(tempsActuel - tempsPrecedent < 100){
        tempsActuel = millis();
        avancer();
      }
      tempsActuel = 0;
      rotation();
      arret();
      //Si le robot 2 se situe aux intersections 2,3,4,6 ou 8, il recoit la position du robot 1
      if (intersection == 2 || intersection == 3 || intersection == 4 || intersection == 6 || intersection == 8) {
        positionR1_recue = false;
        while(positionR1_recue == false){
          if (HC12.available()) {
            msg = HC12.read();
            positionRobot1 = msg - '0';
            positionR1_recue = true;
          }
        }
        //Tant que les robots sont à proximité l'un de l'autre et risquent d'entrer en collision, le robot 2 n'avance pas
        while ((intersection == 2 && (consigneRobot[1] == 'A' || consigneRobot[1] == 'C') && (consigneRobot1 == 'A' || consigneRobot1 == 'C') && (positionRobot1 == 3 || positionRobot1 == 4)) || (intersection == 3 && (consigneRobot[1] == 'B' || consigneRobot[1] == 'D') && (consigneRobot1 == 'B' || consigneRobot1 == 'D') && (positionRobot1 == 4 || positionRobot1 == 5)) || (intersection == 4 && ((consigneRobot[1] == 'A' && consigneRobot1 == 'B') || (consigneRobot[1] == 'C' && consigneRobot1 == 'D')) && positionRobot1 == 6) || (((intersection == 6 && (consigneRobot[1] == 'A' || consigneRobot[1] == 'C')) || (intersection == 8 && (consigneRobot[1] == 'B' || consigneRobot[1] == 'D'))) && ((positionRobot1 == 6 && (consigneRobot1 == 'A' || consigneRobot1 == 'C')) || (positionRobot1 == 8 && (consigneRobot1 == 'B' || consigneRobot1 == 'D'))))){
          arret();
          if (HC12.available()) {
            msg = HC12.read();
            positionRobot1 = msg - '0';
          }
        }
      }
    }
    //Suivi de ligne
    else {
      int erreur = positionVoulue - position;
      int correction = Kp * erreur + Kd * (erreur - erreurPrecedente);
      erreurPrecedente = erreur;
      analogWrite(M2B, constrain(vitesse - correction, 0, 255)); 
      analogWrite(M1B, constrain(vitesse + correction, 0, 255));
    }
  }  
}
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

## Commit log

2023-11-14 creation sous espace rendu des rappots
2023-11-14 mauvais rapport (manque la dernière photo)
2023-12-13 Rename 1er suivi de ligne.gif to 1er suivi de ligne.md
